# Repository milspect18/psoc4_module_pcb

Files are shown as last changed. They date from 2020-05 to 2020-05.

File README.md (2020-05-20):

# PSOC4 Module PCB
A very small footprint PSOC 4000 module for microcontroller projects.

The PSOC4 CY8C4246PVI-DS402 microcontroller includes an integrated low-dropout power regulator which means it can be wired directly to a small 3.7 v lipo battery.  This module includes the necessary de-coupling capacitors to filter input power, as well as a pull-up resistor for the reset line.  The only other thing on the board is a 10-pin 1.27mm 2x5 ARM SWD debug header for firmware loading and debugging.

This project has been uploaded to OSH Park and can be ordered here: https://oshpark.com/shared_projects/bZPw8Fch

The board has been made and tested to work.

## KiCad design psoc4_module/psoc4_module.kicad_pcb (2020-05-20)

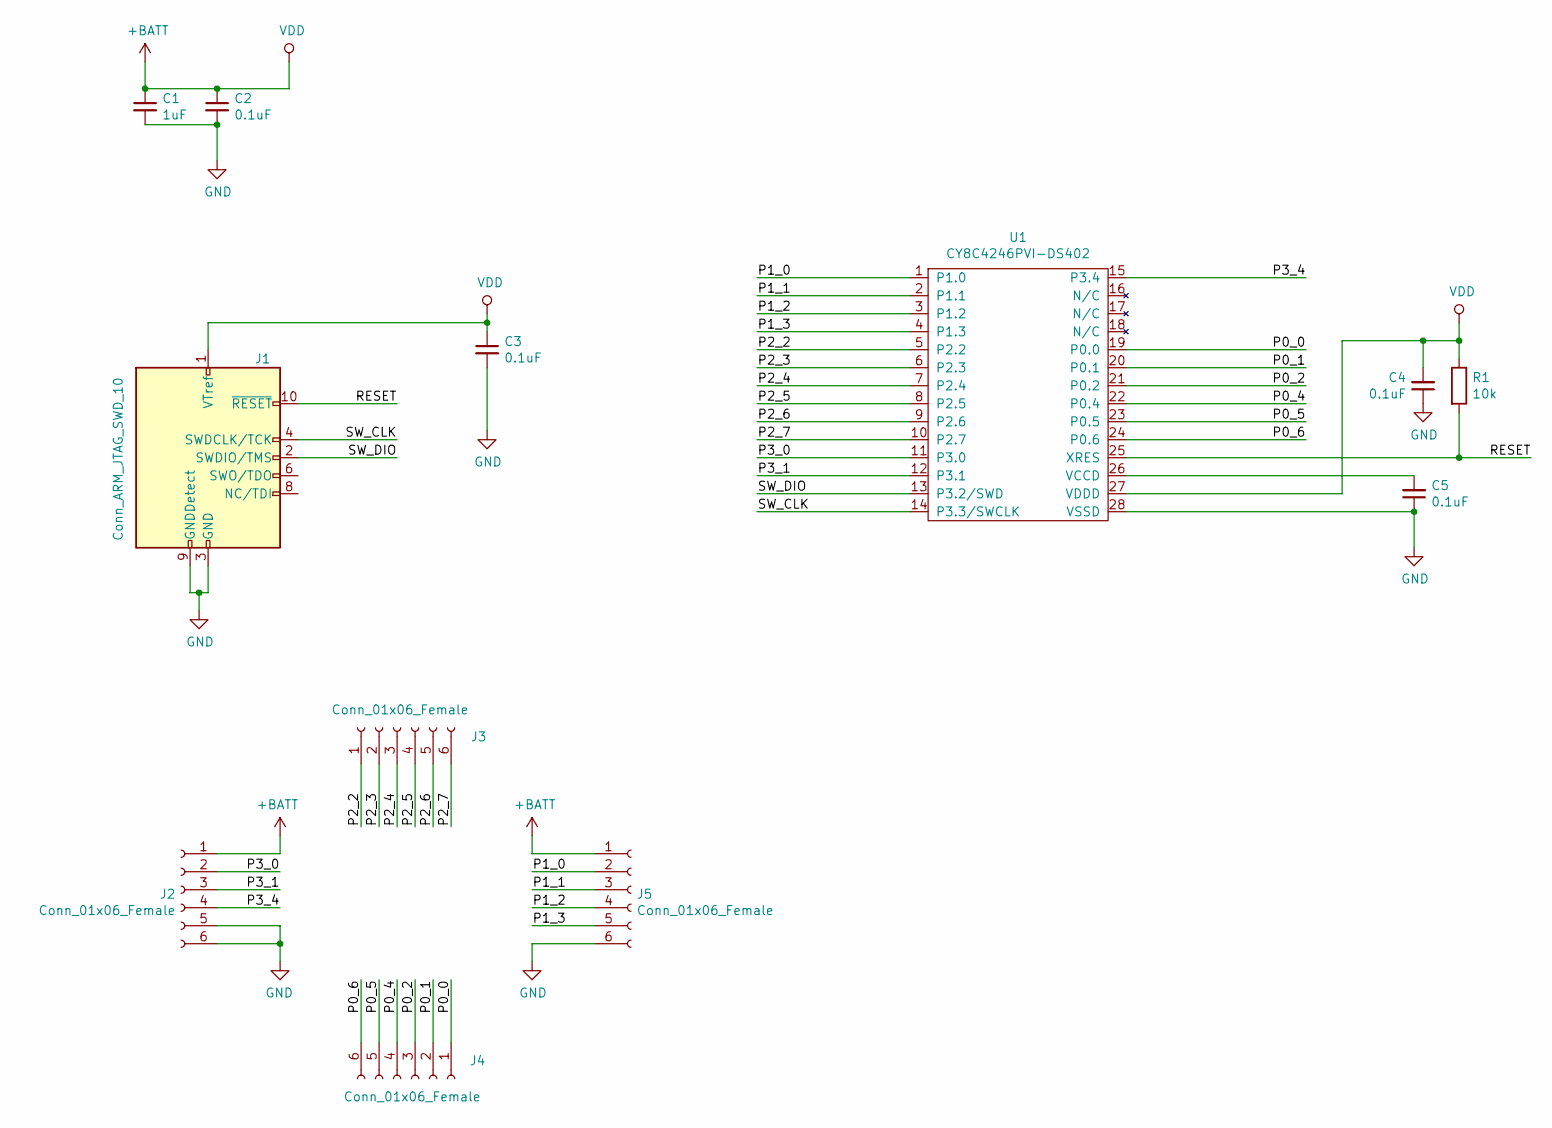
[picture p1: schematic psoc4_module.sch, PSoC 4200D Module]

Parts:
C1: 1uF; C_0603_1608Metric_Pad1.05x0.95mm_HandSolder
C2, C3, C4, C5: 0.1uF; C_0603_1608Metric_Pad1.05x0.95mm_HandSolder
J1: Conn_ARM_JTAG_SWD_10; PinHeader_2x05_P1.27mm_Vertical_SMD
J2, J3, J4, J5: Conn_01x06_Female; 01x06_Casellated
R1: 10k; R_0603_1608Metric_Pad1.05x0.95mm_HandSolder
U1: CY8C4246PVI-DS402; SSOP-28_5.3x10.2mm_P0.65mm

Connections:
+BATT: C1.1, C2.1, C3.1, C4.2, J1.1 (VTref), J2.1, J5.1, R1.1, U1.27 (VDDD)
/P0_0: J4.1, U1.19 (P0.0)
/P0_1: J4.2, U1.20 (P0.1)
/P0_2: J4.3, U1.21 (P0.2)
/P0_4: J4.4, U1.22 (P0.4)
/P0_5: J4.5, U1.23 (P0.5)
/P0_6: J4.6, U1.24 (P0.6)
/P1_0: J5.2, U1.1 (P1.0)
/P1_1: J5.3, U1.2 (P1.1)
/P1_2: J5.4, U1.3 (P1.2)
/P1_3: J5.5, U1.4 (P1.3)
/P2_2: J3.1, U1.5 (P2.2)
/P2_3: J3.2, U1.6 (P2.3)
/P2_4: J3.3, U1.7 (P2.4)
/P2_5: J3.4, U1.8 (P2.5)
/P2_6: J3.5, U1.9 (P2.6)
/P2_7: J3.6, U1.10 (P2.7)
/P3_0: J2.2, U1.11 (P3.0)
/P3_1: J2.3, U1.12 (P3.1)
/P3_4: J2.4, U1.15 (P3.4)
/RESET: J1.10 (~RESET~), R1.2, U1.25 (XRES)
/SW_CLK: J1.4 (SWDCLK/TCK), U1.14 (P3.3/SWCLK)
/SW_DIO: J1.2 (SWDIO/TMS), U1.13 (P3.2/SWD)
GND: C1.2, C2.2, C3.2, C4.1, C5.1, J1.3 (GND), J1.5 (GND), J1.9 (GNDDetect), J2.5, J2.6, J5.6, U1.28 (VSSD)
unnamed: C5.2, U1.26 (VCCD)

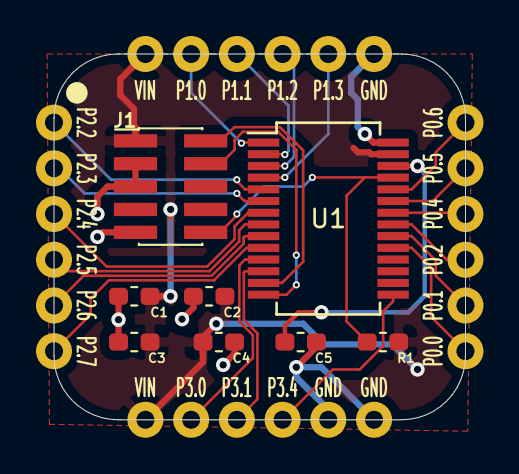
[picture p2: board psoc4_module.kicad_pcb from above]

Board: 2 copper layers, 22.9 x 20.3 mm, 12 parts (0 on the bottom side), 25 nets.

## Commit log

2020-05-20 Add KiCad project and supporting lib components
    [psoc4_module.kicad_pcb, psoc4_module.sch]
2020-05-20 Initial KiCad project and custom lib components
